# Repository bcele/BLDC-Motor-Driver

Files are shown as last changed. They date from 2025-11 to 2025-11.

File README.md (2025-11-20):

# BLDC Motor Driver
Closed-loop BLDC motor driver with PID speed control, ADC-DMA current sensing and 6-step commutation.

## Features
- PID-based speed control
- 6-step commutation
- Dynamic braking and safe-stop handling
- Shunt current sensing via ADC + DMA

## Hardware / Software
- STM32 HAL Libraries
- Custom PCB Design with EAGLE

## Notes
Project supported by TÜBİTAK 2209-B.

### Block Diagram
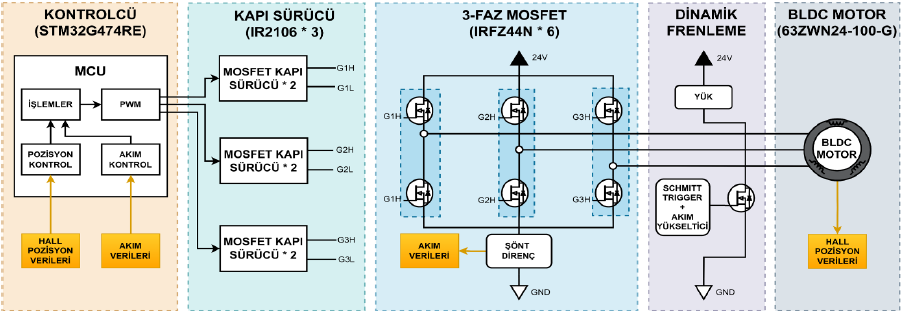
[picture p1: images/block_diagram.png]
Block Diagram


## Hardware

### PCB Layout
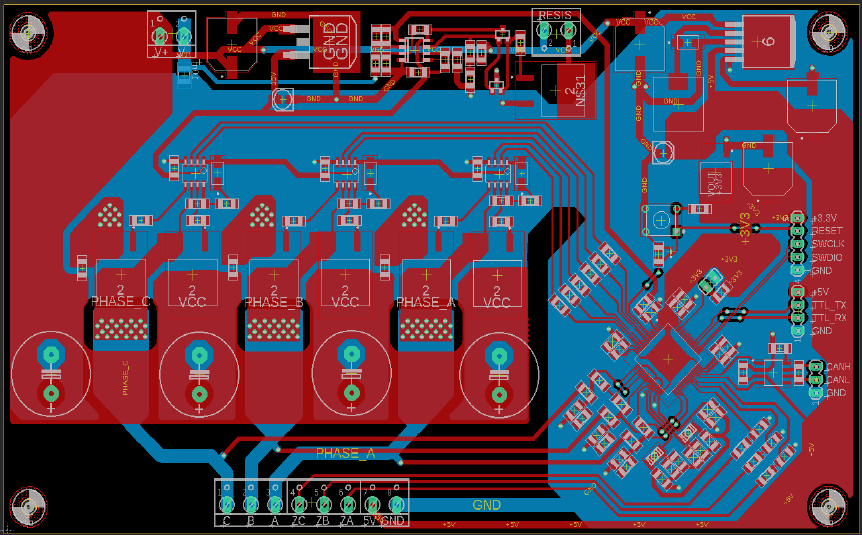
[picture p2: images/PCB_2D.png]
PCB Layout


### Assembled PCB
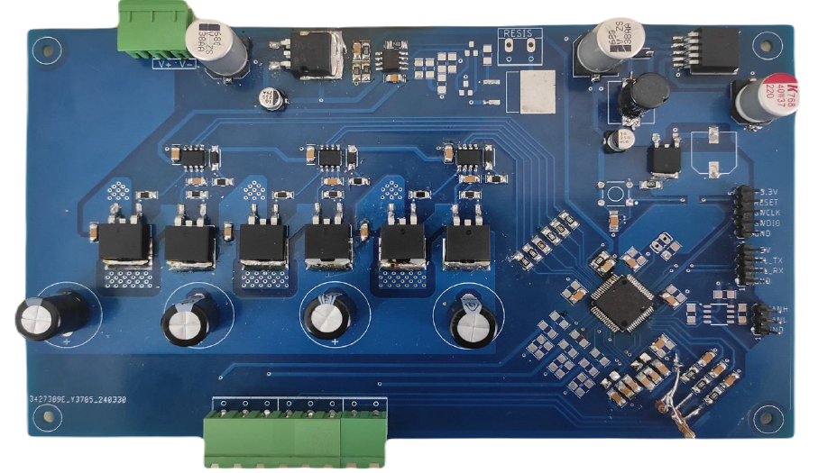
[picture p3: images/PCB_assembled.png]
Assembled PCB


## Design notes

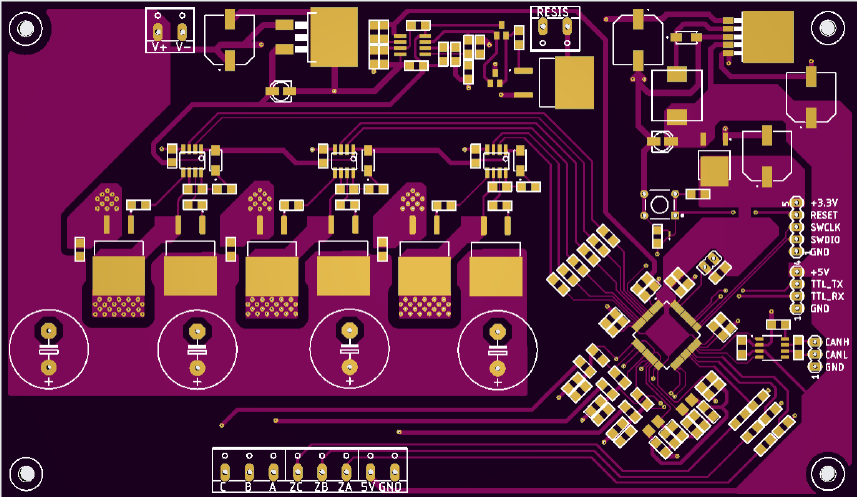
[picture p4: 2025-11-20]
images/PCB_Front.png

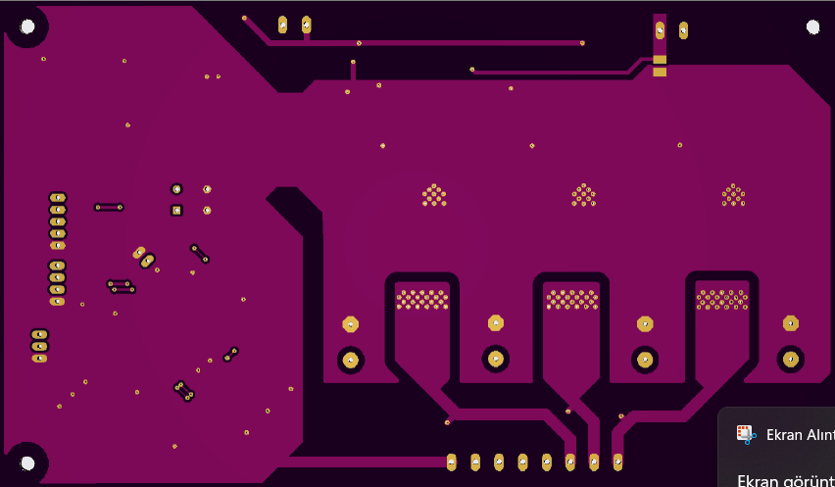
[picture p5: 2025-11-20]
images/PCB_back.png

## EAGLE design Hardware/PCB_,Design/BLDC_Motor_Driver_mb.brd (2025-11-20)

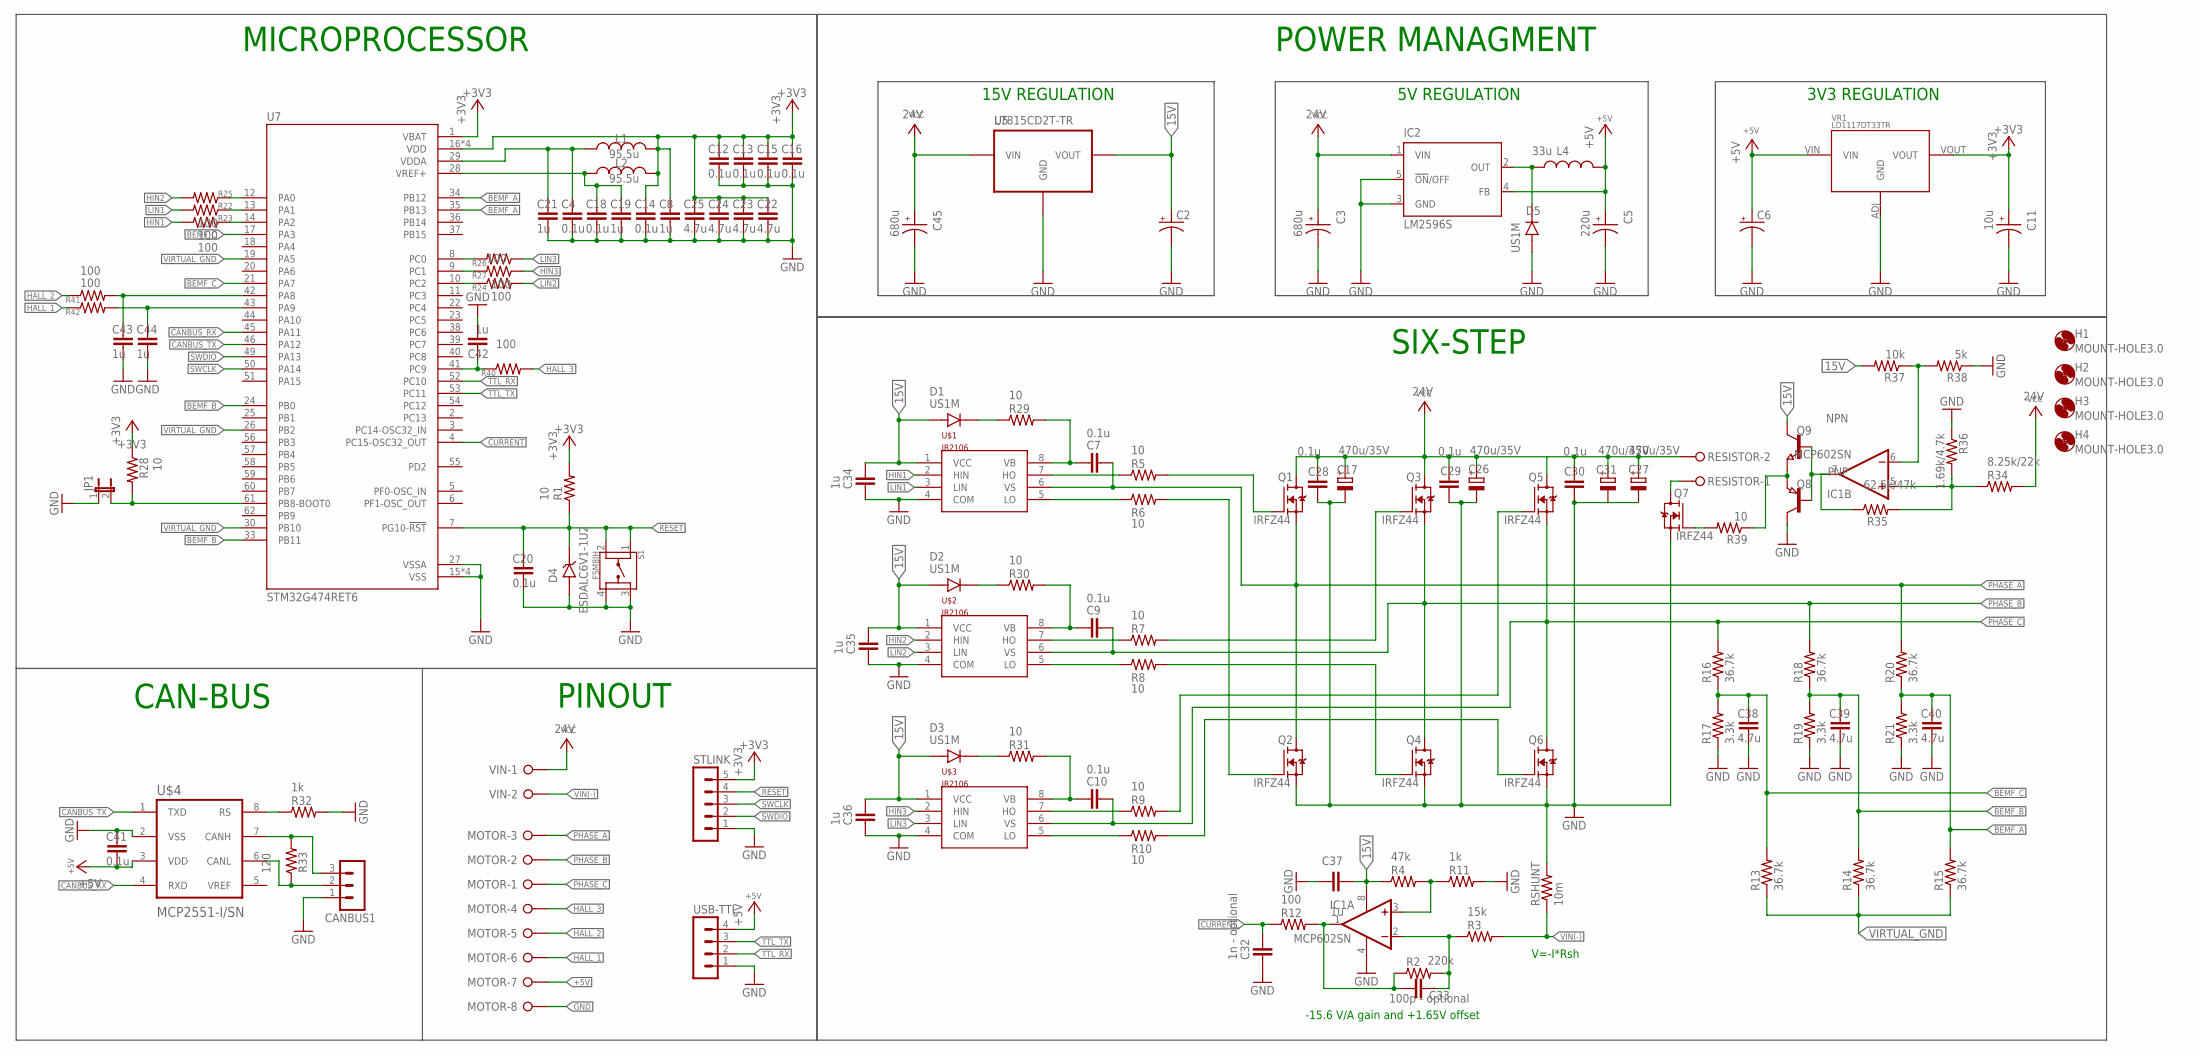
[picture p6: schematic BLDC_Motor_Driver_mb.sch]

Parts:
C2, C6: CPOL-US153CLV-0405; 153CLV-0405
C3, C45: 680u; CAP_EEEFK1H221P
C4, C7, C9, C10, C12, C13, C14, C15, C16, C18, C20, C28, C29, C30, C41: 0.1u; C1206
C5: 220u; CAP_EEEFK1H221P
C8, C19, C21, C34, C35, C36, C37, C42, C43, C44: 1u; C1206
C11: 10u; CAP_EEEFK1H221P
C17, C26, C27, C31: 470u/35V; E7,5-16
C22, C23, C24, C25, C38, C39, C40: 4.7u; C1206
C32: 1n - optional; C1206
C33: 100p - optional; C1206
CANBUS1: MA03-1
D1, D2, D3, D5: US1M; DIOM4325X250N
D4: ESDALC6V1-1U2; DIODE_ESDALC6V1-1U2
H1, H2, H3, H4: MOUNT-HOLE3.0; 3,0
IC1: MCP602SN; SO08
IC2: LM2596S; TO263-5
JP1: JP1E; JP1
L1, L2: 95.5u; L3225P
L4: 33u; IHLP4040
MOTOR: W237-08P; W237-8P
Q1, Q2, Q3, Q4, Q5, Q6, Q7: IRFZ44; DPAK254P1524X483-3N
Q8: PNP; SOT23
Q9: NPN; SOT23
R1, R5, R6, R7, R8, R9, R10, R28, R29, R30, R31, R39: 10; R1206
R2: 220k; R1206
R3: 15k; R1206
R4: 47k; R1206
R11, R32: 1k; R1206
R12, R22, R23, R24, R25, R26, R27, R40, R41, R42: 100; R1206
R13, R14, R15, R16, R18, R20: 36.7k; R1206
R17, R19, R21: 3.3k; R1206
R33: 120; R1206
R34: 8.25k/22k; R1206
R35: 62.5k/47k; R1206
R36: 1.69k/4.7k; R1206
R37: 10k; R1206
R38: 5k; R1206
RESISTOR: W237-02P; W237-132
RSHUNT: 10m; R1210
S1: FSM8JH; SW_FSM8JH
STLINK: MA05-1
U5: L7815CD2T-TR; D2PAK
U7: STM32G474RET6; QFP50P1200X1200X160-64N
U$1, U$2, U$3: IR2106; SOIC-8
U$4: MCP2551-I/SN; SOIC127P599X175-8N
USB-TTL: MA04-1
VIN: W237-02P; W237-132
VR1: LD1117DT33TR; DPAK456P1010X240-3N

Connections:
15V: C2.+, C34.2, C35.2, C36.2, C37.1, D1.A, D2.A, D3.A, IC1.8 (V+), Q9.3 (C), R4.1, R37.2, U5.VOUT, U$1.1 (VCC), U$2.1 (VCC), U$3.1 (VCC)
+3V3: C8.1, C11.1, C12.1, C13.1, C14.1, C15.1, C16.1, C22.1, C23.1, C24.1, C25.1, L1.2, L2.2, R1.2, R28.1, STLINK.5, U7.1 (VBAT), U7.16 (VDD), U7.32 (VDD), U7.48 (VDD), U7.64 (VDD), VR1.VOUT
+5V: C5.1, C6.+, C41.2, IC2.4 (FB), L4.2, MOTOR.7, U$4.3 (VDD), USB-TTL.4, VR1.VIN
BEMF_A: C40.1, R15.2, R20.1, R21.2, U7.34 (PB12), U7.35 (PB13)
BEMF_B: C39.1, R14.2, R18.1, R19.2, U7.24 (PB0), U7.33 (PB11)
BEMF_C: C38.1, R13.2, R16.1, R17.2, U7.17 (PA3), U7.21 (PA7)
CANBUS_RX: U7.45 (PA11), U$4.4 (RXD)
CANBUS_TX: U7.46 (PA12), U$4.1 (TXD)
CURRENT: C32.2, R12.1, U7.4 (PC15-OSC32_OUT)
GND: C2.-, C3.2, C4.2, C5.2, C6.-, C8.2, C11.2, C12.2, C13.2, C14.2, C15.2, C16.2, C17.-, C18.2, C19.2, C20.2, C21.2, C22.2, C23.2, C24.2, C25.2, C26.-, C27.-, C28.2, C29.2, C30.2, C31.-, C32.1, C34.1, C35.1, C36.1, C37.2, C38.2, C39.2, C40.2, C41.1, C42.2, C43.2, C44.2, C45.2, CANBUS1.1, D4.2 (A), D5.A, IC1.4 (V-), IC2.3 (GND), IC2.5 (!ON!/OFF), JP1.1, MOTOR.8, Q2.3 (S), Q4.3 (S), Q6.3 (S), Q7.3 (S), Q8.3 (C), R11.2, R17.1, R19.1, R21.1, R32.2, R36.1, R38.1, RSHUNT.2, S1.3, S1.4, STLINK.1, U5.GND, U7.15 (VSS), U7.27 (VSSA), U7.31 (VSS), U7.47 (VSS), U7.63 (VSS), U$1.4 (COM), U$2.4 (COM), U$3.4 (COM), U$4.2 (VSS), USB-TTL.1, VR1.ADJ (GND)
HALL_1: MOTOR.6, R42.1
HALL_2: MOTOR.5, R41.1
HALL_3: MOTOR.4, R40.2
HIN1: R23.2, U$1.2 (HIN)
HIN2: R25.2, U$2.2 (HIN)
HIN3: R27.1, U$3.2 (HIN)
HS2: Q3.1 (G), R7.2
HS3: Q5.1 (G), R9.2
LIN1: R22.2, U$1.3 (LIN)
LIN2: R24.2, U$2.3 (LIN)
LIN3: R26.1, U$3.3 (LIN)
LS1: Q2.1 (G), R6.2
LS2: Q4.1 (G), R8.2
LS3: Q6.1 (G), R10.2
unnamed: Q1.1 (G), R5.2
unnamed: C4.1, C21.1, L1.1, U7.29 (VDDA)
unnamed: R6.1, U$1.5 (LO)
unnamed: C9.1, R30.2, U$2.8 (VB)
unnamed: R5.1, U$1.7 (HO)
unnamed: R26.2, U7.8 (PC0)
unnamed: D1.C (K), R29.1
unnamed: C7.1, R29.2, U$1.8 (VB)
unnamed: R27.2, U7.9 (PC1)
unnamed: R7.1, U$2.7 (HO)
unnamed: R8.1, U$2.5 (LO)
unnamed: JP1.2, R28.2, U7.61 (PB8-BOOT0)
unnamed: C33.1, IC1.2 (-IN), R2.2, R3.1
unnamed: IC1.3 (+IN), R4.2, R11.1
unnamed: C10.1, R31.2, U$3.8 (VB)
unnamed: IC1.7 (OUT), Q8.1 (B), Q9.1 (B), R35.1
unnamed: R9.1, U$3.7 (HO)
unnamed: R10.1, U$3.5 (LO)
unnamed: D2.C (K), R30.1
unnamed: C18.1, C19.1, L2.1, U7.28 (VREF+)
unnamed: C33.2, IC1.1 (OUT), R2.1, R12.2
unnamed: D5.C (K), IC2.2 (OUT), L4.1
unnamed: R22.1, U7.13 (PA1)
unnamed: R23.1, U7.14 (PA2)
unnamed: R24.1, U7.10 (PC2)
unnamed: R25.1, U7.12 (PA0)
unnamed: D3.C (K), R31.1
unnamed: R32.1, U$4.8 (RS)
unnamed: IC1.5 (+IN), R34.1, R35.2, R36.2
unnamed: CANBUS1.3, R33.2, U$4.7 (CANH)
unnamed: Q7.2 (D), RESISTOR.1
unnamed: CANBUS1.2, R33.1, U$4.6 (CANL)
unnamed: IC1.6 (-IN), R37.1, R38.2
unnamed: Q8.2 (E), Q9.2 (E), R39.1
unnamed: Q7.1 (G), R39.2
unnamed: C42.1, R40.1, U7.41 (PC9)
unnamed: C43.1, R41.2, U7.42 (PA8)
unnamed: C44.1, R42.2, U7.43 (PA9)
PHASE_A: C7.2, MOTOR.3, Q1.3 (S), Q2.2 (D), R20.2, U$1.6 (VS)
PHASE_B: C9.2, MOTOR.2, Q3.3 (S), Q4.2 (D), R18.2, U$2.6 (VS)
PHASE_C: C10.2, MOTOR.1, Q5.3 (S), Q6.2 (D), R16.2, U$3.6 (VS)
RESET: C20.1, D4.1 (K), R1.1, S1.1, S1.2, STLINK.4, U7.7 (PG10-!RST)
SWCLK: STLINK.3, U7.50 (PA14)
SWDIO: STLINK.2, U7.49 (PA13)
TTL_RX: U7.52 (PC10), USB-TTL.2
TTL_TX: U7.53 (PC11), USB-TTL.3
VCC: C3.1, C17.+, C26.+, C27.+, C28.1, C29.1, C30.1, C31.+, C45.1, IC2.1 (VIN), Q1.2 (D), Q3.2 (D), Q5.2 (D), R34.2, RESISTOR.2, U5.VIN, VIN.1
VIN(-): R3.2, RSHUNT.1, VIN.2
VIRTUAL_GND: R13.1, R14.1, R15.1, U7.19 (PA5), U7.26 (PB2), U7.30 (PB10)

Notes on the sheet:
MICROPROCESSOR
SIX-STEP
POWER MANAGMENT
15V REGULATION
5V REGULATION
3V3 REGULATION
PINOUT
-15.6 V/A gain and +1.65V offset
V=-I*Rsh
CAN-BUS

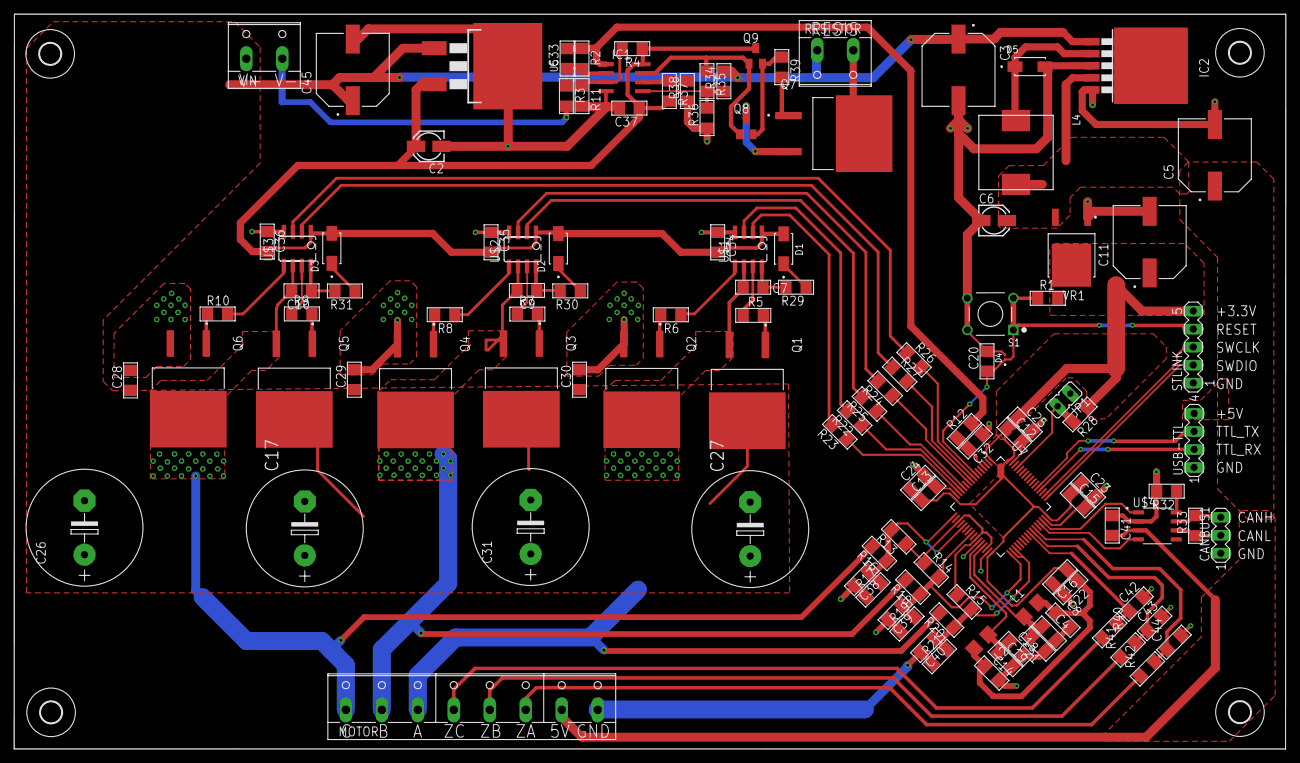
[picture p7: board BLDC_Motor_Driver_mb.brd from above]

Board: 2 copper layers, 179.6 x 103.8 mm, 125 parts (1 on the bottom side), 73 nets.

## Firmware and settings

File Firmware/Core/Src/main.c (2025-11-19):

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
/* Includes ------------------------------------------------------------------*/
#include "main.h"

/* USER CODE BEGIN PM */

#define SPEED_SCALE 	824403.0f
#define TIMER_MAX_COUNT 65536.0
#define CURRENT_SCALE	0.0053f
#define CURRENT_OFFSET	10.1223f

/* USER CODE END PM */

ADC_HandleTypeDef hadc1;
DMA_HandleTypeDef hdma_adc1;

TIM_HandleTypeDef htim1;
TIM_HandleTypeDef htim2;
TIM_HandleTypeDef htim3;

/* USER CODE BEGIN PV */

typedef enum{
	MOTOR_DIR_CCW = 0,
	MOTOR_DIR_CW = 1
}Motor_Direction_t;

typedef struct{
	float kp;
	float ki;
	float integrator;
	float out_min;
	float out_max;
}PI_Controller_t;

uint8_t hall_state = 0;
Motor_Direction_t motor_direction = MOTOR_DIR_CCW;

uint8_t hallA;
uint8_t hallB;
uint8_t hallC;

static volatile uint16_t pwm_duty;
static volatile uint16_t adc_current_raw;

uint16_t hall_pulse_count = 0;
uint16_t ov_count = 0;
uint8_t ov_pending = 0;
uint8_t check_flag = 0;

float hal_period_count = 0.0f;
float hal_period_filtered = 0.0f;
float speed_rpm = 0.0f;
float speed_ref_rpm = 0.0f;

float current = 0.0f;
float current_ref = 0.2f;
float current_limit = 1.0f;

float error_cur = 0.0f, error_speed = 0.0f;
float integ_cur = 0.0f, integ_speed = 0.0f;

float speed_cmd = 0.0f;
float current_cmd = 0.0f;

PI_Controller_t pi_speed = {
		.kp = 1.0f,
		.ki = 1.0f,
		.integrator = 0.0f,
		.out_min = -0.9f,
		.out_max = 0.9f
};

PI_Controller_t pi_current = {
		.kp = 1.0f,
		.ki = 1.0f,
		.integrator = 0.0f,
		.out_min = -7000.0f,
		.out_max = 7000.0f
};

/* USER CODE END PV */

void SystemClock_Config(void);
static void MX_GPIO_Init(void);
static void MX_DMA_Init(void);
static void MX_TIM1_Init(void);
static void MX_TIM2_Init(void);
static void MX_ADC1_Init(void);
static void MX_TIM3_Init(void);
/* USER CODE BEGIN PFP */

static void Update_Hall_Signals(void);
static void Apply_Commutation(void);
static void Disable_Phases(void);
static float PI_Update(PI_Controller_t *pi, float ref, float meas);
static uint8_t Get_Hall_State(void);

/* USER CODE END PFP */

/* USER CODE BEGIN 0 */

void HAL_GPIO_EXTI_Callback(uint16_t GPIO_Pin){

	Update_Hall_Signals();
	Apply_Commutation();

	hall_pulse_count++;
	hal_period_count = __HAL_TIM_GET_COUNTER(&htim3);
	hal_period_filtered = hal_period_filtered * 0.95f + hal_period_count * 0.05f;

	check_flag = 0;
	__HAL_TIM_SET_COUNTER(&htim3, 0);

	if(ov_pending == 1){
		ov_pending = 0;
	}
}

void HAL_ADC_ConvCpltCallback(ADC_HandleTypeDef* hadc)
{
	if(hadc == &hadc1){
		current = adc_current_raw * CURRENT_SCALE - CURRENT_OFFSET;
	}

}

void HAL_TIM_PeriodElapsedCallback(TIM_HandleTypeDef *htim){


	if(htim == &htim3){
		// Check TIM3 overflow
		if(ov_pending == 1){
			ov_count++;
			ov_pending = 0;
		}
		check_flag++;

	}

	if (htim == &htim2){

		if(check_flag >= 1){
			ov_pending++;
			ov_count+=check_flag;
			check_flag = 0;
		}

		if (ov_pending == 0) {speed_rpm = SPEED_SCALE / hal_period_filtered;}
		else {speed_rpm = SPEED_SCALE / (hal_period_filtered + (TIMER_MAX_COUNT * ov_count));}

		// Direction check
		float speed_sign = (motor_direction == MOTOR_DIR_CW) ? 1.0f : -1.0f;
		float speed_rpm_signed = speed_sign * speed_rpm;

		// speeed PI
		speed_cmd = PI_Update(&pi_speed, speed_ref_rpm, speed_rpm_signed);
		current_ref = speed_cmd * current_limit;

		// Current sign check
		float current_signed = current * speed_sign;

		//Current PI
		current_cmd = PI_Update(&pi_current, current_ref, current_signed);

		// Set PWM duty & Motor direction
		if (current_cmd < 0.0f){
			motor_direction = MOTOR_DIR_CCW;
			pwm_duty = - current_cmd;
		}
		else {
			motor_direction = MOTOR_DIR_CW;
			pwm_duty = current_cmd;
		}

		// Set timer CCR registers
		TIM2->CCR1 = pwm_duty;
		TIM2->CCR3 = pwm_duty;
		TIM1->CCR2 = pwm_duty;
	}

}

static void Disable_Phases(void){
	//PA2
	GPIOA->MODER &= ~(0b11 << 4);
	//PA0
	GPIOA->MODER &= ~(0b11 << 0);
	//PC1
	GPIOC->MODER &= ~(0b11 << 2);

	HAL_GPIO_WritePin(LIN_1_GPIO_Port, LIN_1_Pin, GPIO_PIN_RESET);
	HAL_GPIO_WritePin(LIN_2_GPIO_Port, LIN_2_Pin, GPIO_PIN_RESET);
	HAL_GPIO_WritePin(LIN_3_GPIO_Port, LIN_3_Pin, GPIO_PIN_RESET);
}

static void Update_Hall_Signals(void){

	hallA=HAL_GPIO_ReadPin(HALLA_GPIO_Port, HALLA_Pin);
	hallB=HAL_GPIO_ReadPin(HALLB_GPIO_Port, HALLB_Pin);
	hallC=HAL_GPIO_ReadPin(HALLC_GPIO_Port, HALLC_Pin);

}

static void Apply_Commutation(void){

	Disable_Phases();

	uint8_t hall_state = Get_Hall_State();

  switch(hall_state){
  	  //2
	  case 1:
		  GPIOA->MODER |= (0b10 << 4);
		  HAL_GPIO_WritePin(LIN_3_GPIO_Port, LIN_3_Pin, GPIO_PIN_SET);
		  break;

	  //4
	  case 2:
		 GPIOA->MODER |= (0b10 << 0);
		  HAL_GPIO_WritePin(LIN_1_GPIO_Port, LIN_1_Pin, GPIO_PIN_SET);
		  break;

	  //3
	  case 3:
		  GPIOA->MODER |= (0b10 << 0);
		  HAL_GPIO_WritePin(LIN_3_GPIO_Port, LIN_3_Pin, GPIO_PIN_SET);
		  break;

	  //6
	  case 4:
		  GPIOC->MODER |= (0b10 << 2);
		  HAL_GPIO_WritePin(LIN_2_GPIO_Port, LIN_2_Pin, GPIO_PIN_SET);
		  break;

	  //1
	  case 5:
		  GPIOA->MODER |= (0b10 << 4);
		  HAL_GPIO_WritePin(LIN_2_GPIO_Port, LIN_2_Pin, GPIO_PIN_SET);
		  break;

	  //5
	  case 6:
		  GPIOC->MODER |= (0b10 << 2);
		  HAL_GPIO_WritePin(LIN_1_GPIO_Port, LIN_1_Pin, GPIO_PIN_SET);
		  break;

	  default:
		  break;
	  }
}

static float PI_Update(PI_Controller_t *pi, float ref, float meas){
	float error = ref - meas;
	pi->integrator += pi->ki * error;

	if (pi->integrator >= pi->out_max) { pi->integrator = pi->out_max; }
	if (pi->integrator <= pi->out_min) { pi->integrator = pi->out_min; }

	float out = pi->kp * error + pi->integrator;

	if (out >= pi->out_max) { out = pi->out_max; }
	if (out <= pi->out_min) { out = pi->out_min; }

	return out;
}

static uint8_t Get_Hall_State(void){
    uint8_t state = 0U;

    if (hall_a) state |= 0x1U;
    if (hall_b) state |= 0x2U;
    if (hall_c) state |= 0x4U;

    if (motor_direction == MOTOR_DIR_CW) {
        state = 7U - state;
    }

    return state;
}

/* USER CODE END 0 */

/**
  * @brief  The application entry point.
  * @retval int
  */
int main(void)
{

  /* MCU Configuration--------------------------------------------------------*/

  /* Reset of all peripherals, Initializes the Flash interface and the Systick. */
  HAL_Init();

  /* Configure the system clock */
  SystemClock_Config();

  /* Initialize all configured peripherals */
  MX_GPIO_Init();
  MX_DMA_Init();
  MX_TIM1_Init();
  MX_TIM2_Init();
  MX_ADC1_Init();
  MX_TIM3_Init();
  /* USER CODE BEGIN 2 */
  HAL_TIM_PWM_Start(&htim1, TIM_CHANNEL_2);
  HAL_TIM_PWM_Start(&htim2, TIM_CHANNEL_1);
  HAL_TIM_PWM_Start(&htim2, TIM_CHANNEL_3);

  HAL_TIM_Base_Start_IT(&htim2);
  HAL_TIM_Base_Start_IT(&htim3);

  TIM2->CCR1 = pwm_duty;
  TIM2->CCR3 = pwm_duty;
  TIM1->CCR2 = pwm_duty;

  HAL_ADCEx_Calibration_Start(&hadc1, ADC_SINGLE_ENDED);
  HAL_ADC_Start_DMA(&hadc1, (uint32_t*)&adc_current_raw, 1);


  Calc_HALLState();
  Calc_SwitchState();
  /* USER CODE END 2 */

  /* Infinite loop */
  /* USER CODE BEGIN WHILE */

  while (1)
  {
    /* USER CODE END WHILE */

    /* USER CODE BEGIN 3 */
  }
  /* USER CODE END 3 */
}

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


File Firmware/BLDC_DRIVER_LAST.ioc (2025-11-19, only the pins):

Mcu.UserName=STM32G474RETx
PA0.Signal=S_TIM2_CH1
PA1.GPIO_Label=LIN_1
PA1.Signal=GPIO_Output
PA10.GPIO_Label=HALLA
PA10.Signal=GPXTI10
PA2.Signal=S_TIM2_CH3
PA8.GPIO_Label=HALLB
PA8.Signal=GPXTI8
PA9.Signal=GPIO_Input
PC0.GPIO_Label=LIN_3
PC0.Signal=GPIO_Output
PC1.Signal=S_TIM1_CH2
PC15-OSC32_OUT.Signal=GPIO_Input
PC2.GPIO_Label=LIN_2
PC2.Signal=GPIO_Output
PC9.GPIO_Label=HALLC
PC9.Signal=GPXTI9
PF0-OSC_IN.Signal=ADC1_IN10

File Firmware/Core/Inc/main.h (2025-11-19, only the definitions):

#define LIN_3_Pin GPIO_PIN_0
#define LIN_3_GPIO_Port GPIOC
#define LIN_2_Pin GPIO_PIN_2
#define LIN_2_GPIO_Port GPIOC
#define LIN_1_Pin GPIO_PIN_1
#define LIN_1_GPIO_Port GPIOA
#define HALLC_Pin GPIO_PIN_9
#define HALLC_GPIO_Port GPIOC
#define HALLC_EXTI_IRQn EXTI9_5_IRQn
#define HALLB_Pin GPIO_PIN_8
#define HALLB_GPIO_Port GPIOA
#define HALLB_EXTI_IRQn EXTI9_5_IRQn
#define HALLA_Pin GPIO_PIN_10
#define HALLA_GPIO_Port GPIOA
#define HALLA_EXTI_IRQn EXTI15_10_IRQn

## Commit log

2025-11-20 Move STM32 firmware into Firmware directory
2025-11-20 Add BLDC motor driver PCB (Eagle schematics & board)
    [BLDC_Motor_Driver_mb.brd, BLDC_Motor_Driver_mb.sch]

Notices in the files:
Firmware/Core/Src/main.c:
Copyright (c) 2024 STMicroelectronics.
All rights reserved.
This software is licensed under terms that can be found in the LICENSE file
